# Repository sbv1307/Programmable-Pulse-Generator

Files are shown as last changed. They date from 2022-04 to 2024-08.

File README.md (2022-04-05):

# Programmable pulse generator for Arduino.
 The sketch will be build for Arduino NANO 

 The Programmable Pulse Generate will generate pulses on a number of output pins.

 ## Programming
 The Programmable Pulse Generate uses a REST approch over the serial connection (see below). 

  Programmeable parameters:
 - Number of output pins (with a maximum of 10).
 - Puls length in millis for each channel.
 - Puls period in millis for each channel.<span id="a1">[[1]](#f1)</span>
 - The pause between pulses in each channel "Pulse Order Interval".
 - Relation between pulses on the various channels (pulseOrder). 
   - Individual     'I' Pulses starts Simultaneously, but act upon their own pulse length and interval. (Default)
   - Simultaneously 'S' All pulses starts a the same time. Pulse interval is redefined to be the lognest pulse length plus the longest pulse interval.
   - Sequential     'Q' Pulses starts after another), with a programmable pause between the pulses (Pulse Order Interval). 
   - Randum         'R' Pulses starts randumly om each channel and follow their own length and interval.
 - The pulse length on each channel can be selected as LOW pulse or HIGH pulse.
 - Number of pulses fired on each channel. Initiated by a push button function attached to pin A5 (19).
   When the push button is pressed once, the pulse generator stops.
   When the push button is pressed twice, the pulse generator restarts, at fires the configured pulses on each channel.
   When the push button is pressed once, after it has been pushed twice, the pusle generator restarts and runs infinitly.
   
 ### **Firmware Version histoty:**
 * 1.2.4 - Bugfix: Cannot set pulseLength. [if ( value = 0 ... changed to  if ( value >= 0 ...] Value would never be zero:-)
 * 1.2.3 - Bugfix in Sequencial run and documentatino update
 * 1.2.2 - Parameter for programmelable delay after "Run Infinite" to "Run Limited"
 * 1.2.1 - Issues regarding configurations being changed, when Puls Order is changed from I to Q, S or R. handleRest() si change to reload the stored configuration, before adding changes.
 * 1.2.0 - Configuration bugfixes
 * 1.1.2 - Minor documentation corrections - No funktional changes

 * 1.1.0 - Adding push button funktionality, which will fire a configured number of pulses on each channel.
 * 1.0.0 - Prod. version.
 * 0.2.0 - Versions 0.2.x is for developing Programmable interface.
         - Taking the REST approch for programming parameters. 
 * 0.1.1 - Building in funktionality for handeling different "pulse orders".
         - pinState re-defined to match ACTIVE / PASSIVE pulse instead of LOW / HIGH.
 * 0.1.0 - Initial commit: Basic funktionalites are build in. No parameters are programmable, but the required program structure is in place.

#### REST Approch
 * Communication will be over serial connection (USB).
 * When not connected, the sketch will start, using the last programmed configuration.

/configurations/{parameret}/{id}/{value} or /configurations/{parameret}/{value} 

                <numberOfChannels>  /<1 - 10> 
                <pulseOrder>        /<I, S, Q or R>
                <pulseOrderInterval>/<millisecunds>
                <pulseLength>       /<channel 1-10>/<millisecunds>
                <pulsePeriod>       /<channel 1-10>/<millisecunds>
                <pulseActive>       /<channel 1-10>/<LOW or HIGH>
                <numberOfPulses>    /<channel 1-10>/<1 - 100000>
                setDefaults

 ##### Configuration examaples:
 * configurations/numberOfChannels/3
 * configurations/pulseOrder/S
 * configurations/pulseOrderInterval/250
 * configurations/pulseLength/1/100
 * configurations/pulsePeriod/1/500<span id="a1">[[1]](#f1)</span>
 * configurations/pulseActive/1/HIGH
 * configurations/numberOfPulses/1/1000
 * configurations/setDefaults

##### Ardhino nano Pin definition/layout:***
 * Pin  0: Serial RX
 * Pin  1: Serial TX
 * Pin  2: Channel pin 1:
 * Pin  3: Channel pin 2: 
 * Pin  4: Channel pin 3:
 * Pin  5: Channel pin 4:
 * Pin  6: Channel pin 5:
 * Pin  7: Channel pin 6:
 * Pin  8: Channel pin 7:
 * Pin  10: Channel pin 9:
 * Pin  11: Channel pin 10:
 * Pin  12: Channel pin 11:
 * Pin  13: LED_BUILTIN. 
 * Pin  14: (A0): RANDUM_SEED_PIN    Used for randumSeed() to generate different seed numbers each time the sketch runs.
 * Pin  15: (A1): N/C
 * Pin  16: (A2): N/C
 * Pin  17: (A3): N/C
 * Pin  18: (A4): N/C
 * Pin  19: (A5): Button pin. Button to running in non continoougious mode (file configured numer of pulses)

### Project eligibility. 
The sketch was build for simulating the pulses on the open collector outputs on a number of Carlo Gavazzi energy meters Type EM23 DIN and Type EM111.
The project "EnergyRegistgration", which are build to register pulses on the open collector output on the above mentined meters has a problem, counting the pulses corectly. Some pulses are rigistered but not counted and some are counted too many.
This project is to investigate into this problem.

##### 1. <span id="f1"></span>Note: If pulseOrder is set to 'Q', puls period on channel 1 will define the pause from the last puls in the sequence to the first starts. 

### **Project Version History:**
2.0.0 - Hardware merged with Firmware (initial product version)

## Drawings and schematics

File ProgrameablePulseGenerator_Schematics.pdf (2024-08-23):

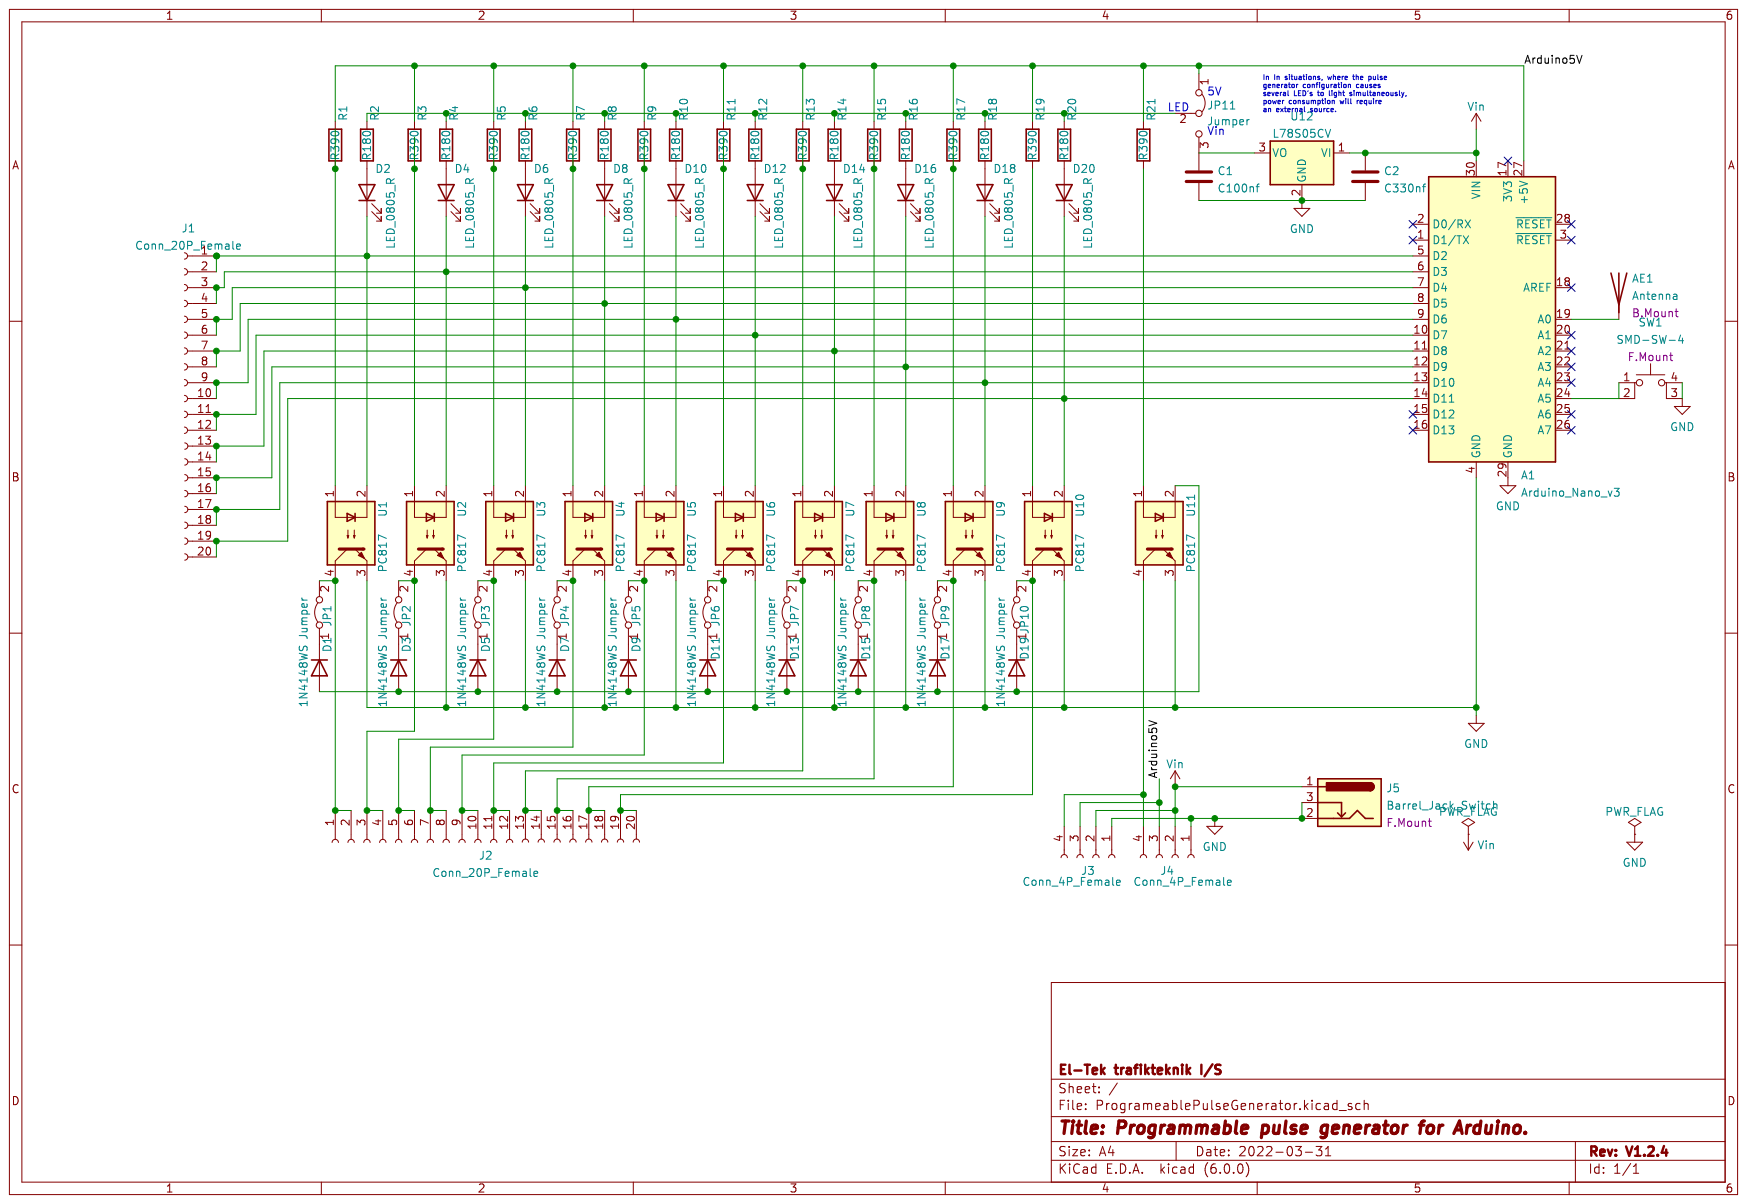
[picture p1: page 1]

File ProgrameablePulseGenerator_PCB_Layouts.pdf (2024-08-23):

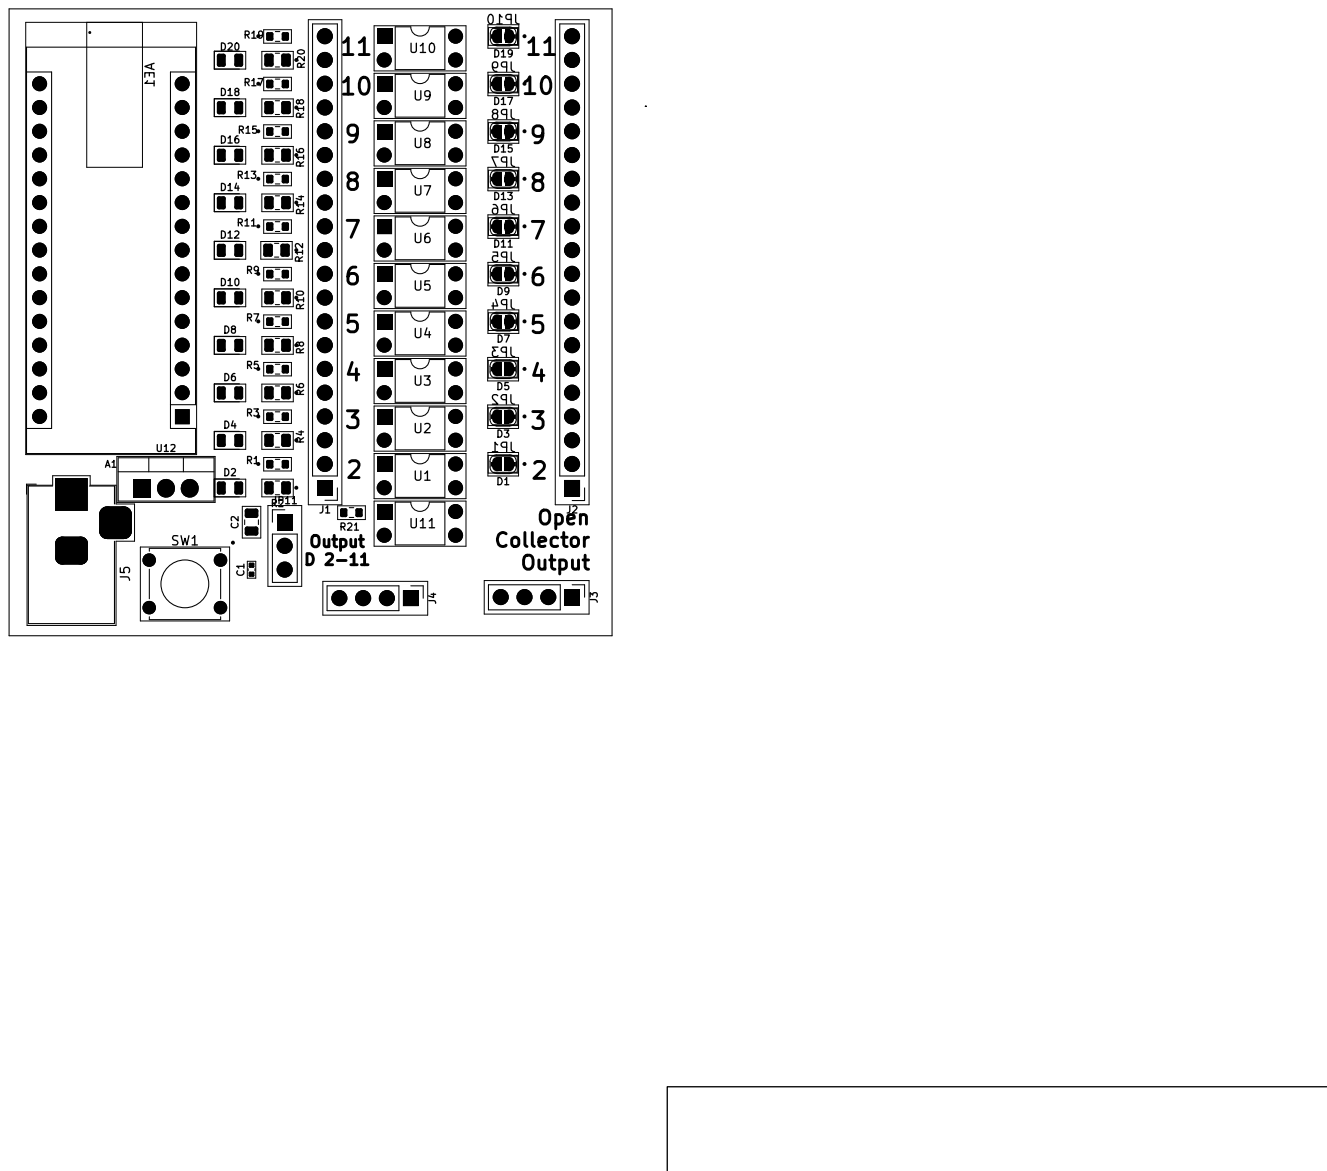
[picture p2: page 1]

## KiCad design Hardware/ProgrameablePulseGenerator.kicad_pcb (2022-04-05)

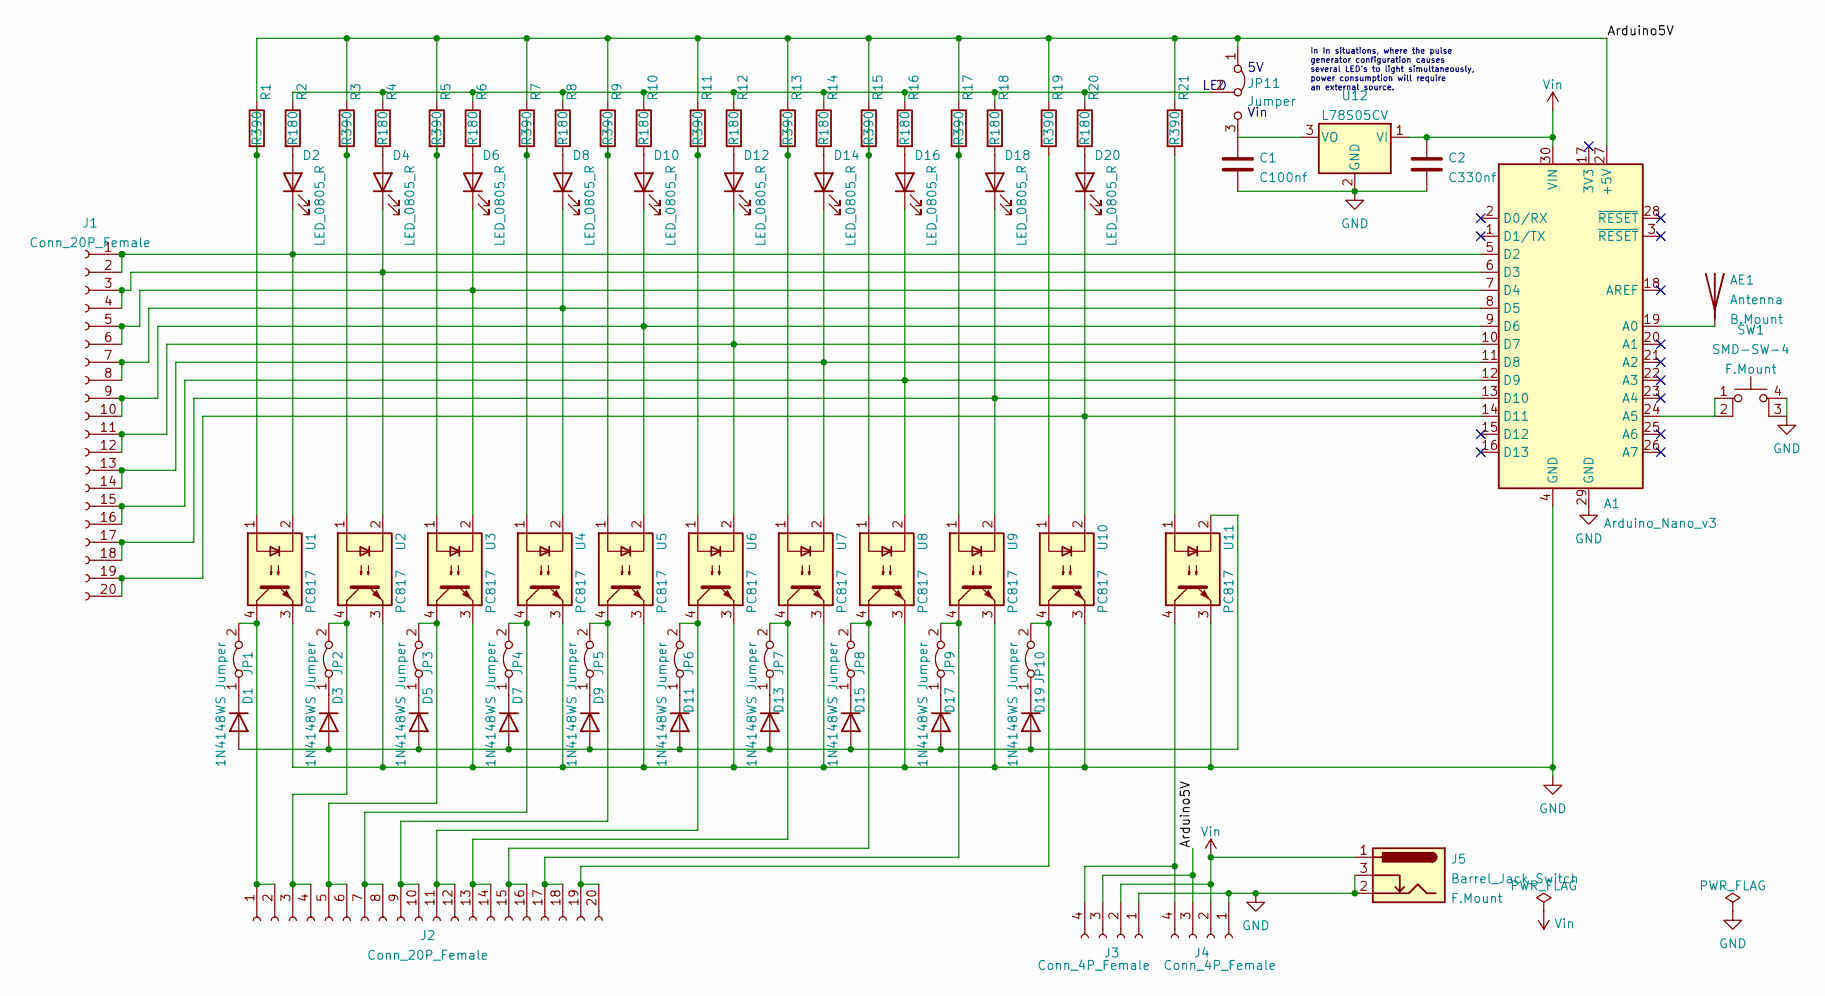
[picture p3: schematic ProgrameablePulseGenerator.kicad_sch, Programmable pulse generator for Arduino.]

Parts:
A1: Arduino_Nano_v3; Arduino_Nano; MFR. Part # A000005; Digi-Key Part # 1050-1001-ND
AE1: Antenna; Undefined_Antenna(B.Mount)
C1: C100nf; C_0402_1005Metric; MFR. Part # CL05B104KO5NNNC; JLCPCB Part # C1525
C2: C330nf; C_0805_2012Metric; MFR. Part # 0805B334K500NT; JLCPCB Part # C1740
D1, D3, D5, D7, D9, D11, D13, D15, D17, D19: 1N4148WS; D_SOD-323F; MFR. Part # 1N4148WS; JLCPCB Part # C2128
D2, D4, D6, D8, D10, D12, D14, D16, D18, D20: LED_0805_R; LED_0805_2012Metric; MFR. Part # NCD0805R1; JLCPCB Part # C84256
J1, J2: Conn_20P_Female; PinHeader_1x20_P2.54mm_Vertical; MFR. Part # 4155; Digi-Key Part # 1528-2927-ND
J3, J4: Conn_4P_Female; PinHeader_1x04_P2.54mm_Vertical; MFR. Part # 4155; Digi-Key Part # 1528-2927-ND
J5: Barrel_Jack_Switch; BarrelJack_Horizontal(F.Mount); MFR. Part # PJ-058AH; Digi-Key Part # CP-058AH-ND
JP1, JP2, JP3, JP4, JP5, JP6, JP7, JP8, JP9, JP10: Jumper; SolderJumper-2_P1.3mm_Bridged_RoundedPad1.0x1.5mm(B.Mount)
JP11: Jumper; PinHeader_1x03_P2.54mm_Vertical
R1, R3, R5, R7, R9, R11, R13, R15, R17, R19, R21: R390; R_0603_1608Metric; MFR. Part # 0603WAF3900T5E; JLCPCB Part # C23151
R2, R4, R6, R8, R10, R12, R14, R16, R18, R20: R180; R_0805_2012Metric; MFR. Part # 0805W8F1800T5E; JLCPCB Part # C25270
SW1: SMD-SW-4; SW_Tactile_Straight_(F.Mount); MFR. Part # TS-1187A-B-A-B; JLCPCB Part # C318884
U1, U2, U3, U4, U5, U6, U7, U8, U9, U10, U11: PC817; DIP-4_W7.62mm_Slim
U12: L78S05CV; TO-220-3_Vertical; MFR. Part # L78S05CV; Digi-Key Part # 497-1468-5-ND

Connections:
/Arduino5V: A1.27 (+5V), J3.3, J4.3, JP11.1 (A), R1.1, R3.1, R5.1, R7.1, R9.1, R11.1, R13.1, R15.1, R17.1, R19.1, R21.1
GND: A1.4 (GND), A1.29 (GND), C1.2, C2.2, J3.1, J4.1, J5.2, J5.3, SW1.3 (K), SW1.4 (A), U1.3, U2.3, U3.3, U4.3, U5.3, U6.3, U7.3, U8.3, U9.3, U10.3, U11.3, U12.2 (GND)
unnamed: A1.5 (D2), D2.1 (K), J1.1, J1.2, U1.2
unnamed: A1.6 (D3), D4.1 (K), J1.3, J1.4, U2.2
unnamed: A1.7 (D4), D6.1 (K), J1.5, J1.6, U3.2
unnamed: A1.8 (D5), D8.1 (K), J1.7, J1.8, U4.2
unnamed: A1.9 (D6), D10.1 (K), J1.9, J1.10, U5.2
unnamed: A1.10 (D7), D12.1 (K), J1.11, J1.12, U6.2
unnamed: A1.11 (D8), D14.1 (K), J1.13, J1.14, U7.2
unnamed: A1.12 (D9), D16.1 (K), J1.15, J1.16, U8.2
unnamed: A1.13 (D10), D18.1 (K), J1.17, J1.18, U9.2
unnamed: A1.14 (D11), D20.1 (K), J1.19, J1.20, U10.2
unnamed: A1.19 (A0), AE1.1 (A)
unnamed: A1.24 (A5), SW1.1, SW1.2
unnamed: C1.1, JP11.3 (B), U12.3 (VO)
unnamed: D1.1 (K), JP1.1 (A)
unnamed: D1.2 (A), D3.2 (A), D5.2 (A), D7.2 (A), D9.2 (A), D11.2 (A), D13.2 (A), D15.2 (A), D17.2 (A), D19.2 (A), U11.2
unnamed: D2.2 (A), R2.2
unnamed: D3.1 (K), JP2.1 (A)
unnamed: D4.2 (A), R4.2
unnamed: D5.1 (K), JP3.1 (A)
unnamed: D6.2 (A), R6.2
unnamed: D7.1 (K), JP4.1 (A)
unnamed: D8.2 (A), R8.2
unnamed: D9.1 (K), JP5.1 (A)
unnamed: D10.2 (A), R10.2
unnamed: D11.1 (K), JP6.1 (A)
unnamed: D12.2 (A), R12.2
unnamed: D13.1 (K), JP7.1 (A)
unnamed: D14.2 (A), R14.2
unnamed: D15.1 (K), JP8.1 (A)
unnamed: D16.2 (A), R16.2
unnamed: D17.1 (K), JP9.1 (A)
unnamed: D18.2 (A), R18.2
unnamed: D19.1 (K), JP10.1 (A)
unnamed: D20.2 (A), R20.2
unnamed: J2.1, J2.2, JP1.2 (B), U1.4
unnamed: J2.3, J2.4, JP2.2 (B), U2.4
unnamed: J2.5, J2.6, JP3.2 (B), U3.4
unnamed: J2.7, J2.8, JP4.2 (B), U4.4
unnamed: J2.9, J2.10, JP5.2 (B), U5.4
unnamed: J2.11, J2.12, JP6.2 (B), U6.4
unnamed: J2.13, J2.14, JP7.2 (B), U7.4
unnamed: J2.15, J2.16, JP8.2 (B), U8.4
unnamed: J2.17, J2.18, JP9.2 (B), U9.4
unnamed: J2.19, J2.20, JP10.2 (B), U10.4
unnamed: J3.4, J4.4, U11.4
unnamed: JP11.2 (C), R2.1, R4.1, R6.1, R8.1, R10.1, R12.1, R14.1, R16.1, R18.1, R20.1
unnamed: R1.2, U1.1
unnamed: R3.2, U2.1
unnamed: R5.2, U3.1
unnamed: R7.2, U4.1
unnamed: R9.2, U5.1
unnamed: R11.2, U6.1
unnamed: R13.2, U7.1
unnamed: R15.2, U8.1
unnamed: R17.2, U9.1
unnamed: R19.2, U10.1
unnamed: R21.2, U11.1
Vin: A1.30 (VIN), C2.1, J3.2, J4.2, J5.1, U12.1 (VI)

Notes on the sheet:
LED
In In situations, where the pulse generator configuration causes several LED's to light simultaneously, power consumption will require an external source.
Vin

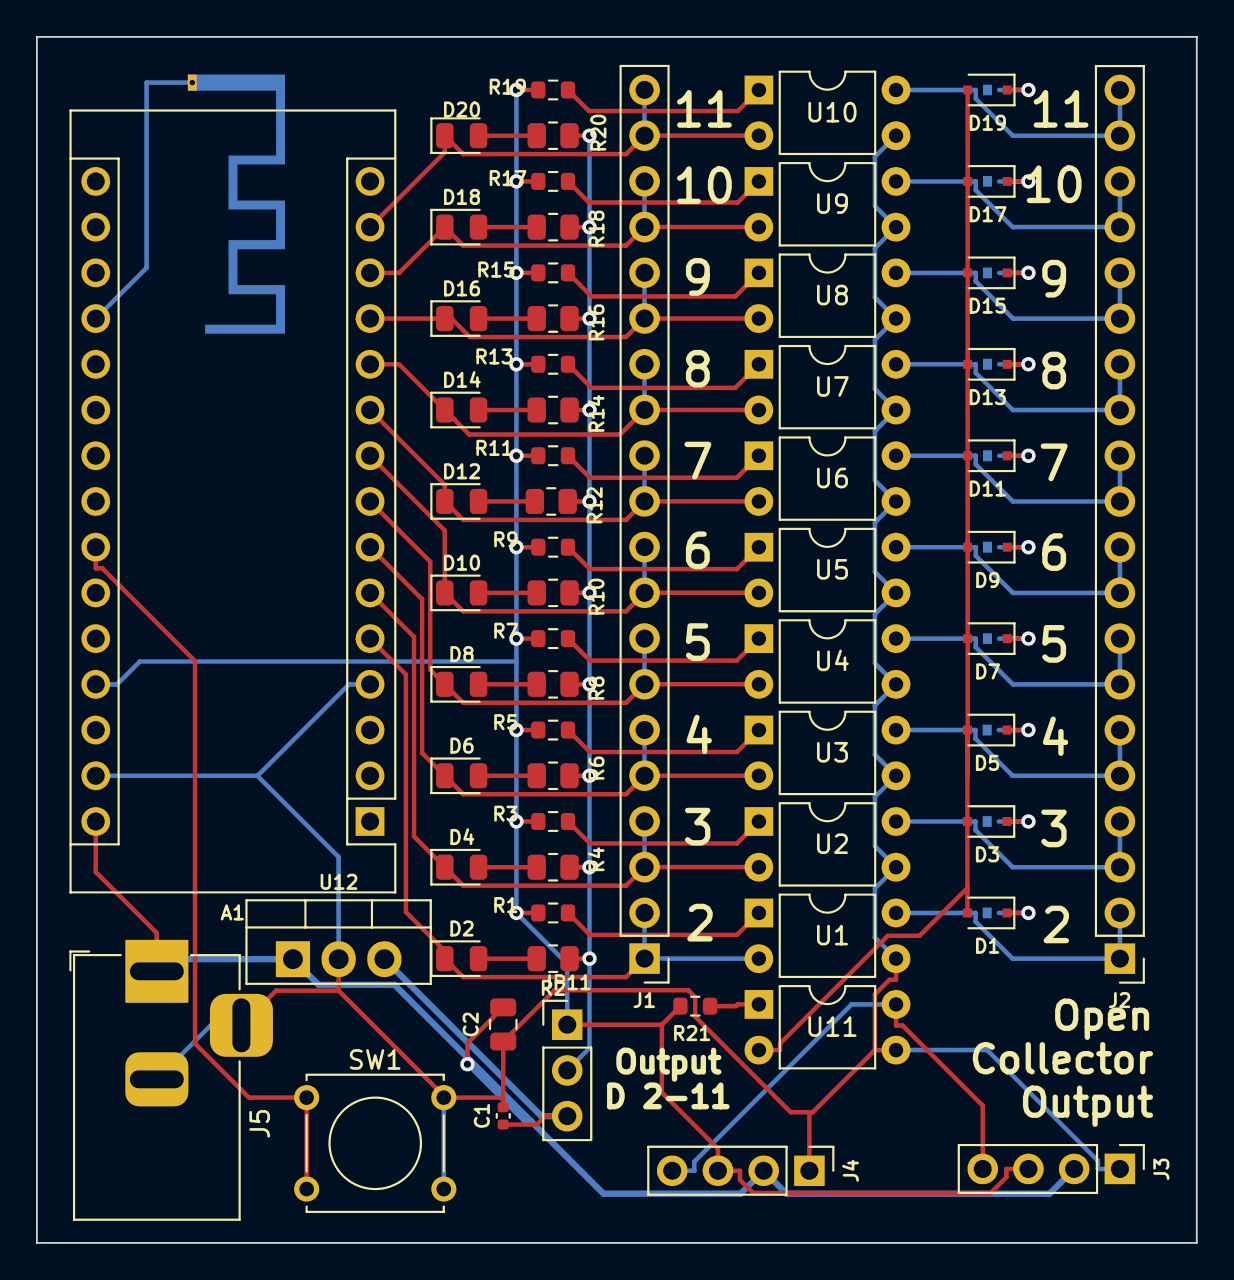
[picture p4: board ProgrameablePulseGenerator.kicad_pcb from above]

Board: 2 copper layers, 64.4 x 67.0 mm, 74 parts (0 on the bottom side), 60 nets.

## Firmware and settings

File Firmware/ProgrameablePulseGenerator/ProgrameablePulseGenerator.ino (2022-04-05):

/*
 * Programable puls generator.
 * 
 * It will generate pulses on a number of output pins. 
 * 
 * Programmable parameters:
 * Parameters are and their defaults:
 * - Number of 
 * channels (MAX 10):           1 
 * - Pulse length in millis:                50
 * - Pulse interval in millis:              1000
 * - Pulse order interval in millis:        250
 * - Number of pulses:                      1
 * - Run continously:                       true
 * - Pulse (the short part / Active part):  LOW
 * - Pulse order:                           Individual (I) 
 *  
 * - Pulse order - Relation between pulses on the various channels. 
 *   : Individual 'I' Pulses act upon their own pulse length and interval (Default).
 *   : Sequential 'Q' Pulses starts after another), with a programmable pause (Pulse order interval) between the pulses. 
 *   : Simultaneously 'S' All pulses starts a the same time.
 *   : Randum 'R' Pulses starts randumly om each channel and follow their own length and interval.
 * 
 */
#define SKETCH_VERSION "Programable puls generator - Version 1.2.4"

/*
 *    Define DEBUGGING
 */
// #define DEBUG       //If defined ("//" is removed at the beginning of this line.) debug informations are printed to Serial.
// #define PULSE_DEBUG // If defined output state for each channel is displayed. (Gives a lot of output...) 
/*
 * Version history:
 * 1.2.4 - Bugfix: Cannot set pulseLength. [if ( value = 0 ... changed to  if ( value >= 0 ...] Value would never be zero:-)
 * 1.2.3 - Bugfix in Sequencial run and documentatino update
 * 1.2.2 - Parameter for programmelable delay after "Run Infinite" to "Run Limited"
 * 1.2.1 - Issues regarding configurations being changed, when Puls Order is changed from I to Q, S or R. handleRest() si change to reload the stored configuration, before adding changes.
 * 1.2.0 - Configuration bugfixes - Configuration defaults change to confiture alle MAX_NUMBER_OF_CHANNELS channels.
 * 1.1.2 - Minor documentation corrections - No funktional changes
 * 1.1.1 - Documentation update - No funktional changes
 * 1.1.0 - Adding push button funktionality, which will fire a configured number of pulses on each channel. 
 *       - Configuration structure is changed.
 * 1.0.0 - Prod. version.
 * 0.2.0 - Versions 0.2.x is for developing Programmable interface.
 *       - 
 * 0.1.1 - Building in funktionality for handeling different "pulse orders".
 * 0.1.0 - Initial commit: Basic funktionalites are build in. No parameters are programmable, but the required program structure is in place.
 * 
 * 
 *  **** Ardhino nano Pin definition/layout:***
 * Pin  D0: Serial RX
 * Pin  D1: Serial TX
 * Pin  D2: Channel pin 1:
 * Pin  D3: Channel pin 2: 
 * Pin  D4: Channel pin 3:
 * Pin  D5: Channel pin 4:
 * Pin  D6: Channel pin 5:
 * Pin  D7: Channel pin 6:
 * Pin  D8: Channel pin 7:
 * Pin  D10: Channel pin 9:
 * Pin  D11: Channel pin 10:
 * Pin  D12: Channel pin 11:
 * Pin  D13: LED_BUILTIN. 
 * Pin  D14: (A0): RANDUM_SEED_PIN    Used for randumSeed() to generate different seed numbers each time the sketch runs.
 * Pin  D15: (A1): N/C
 * Pin  D16: (A2): N/C
 * Pin  D17: (A3): N/C
 * Pin  D18: (A4): N/C
 * Pin  D19: (A5): Button pin. Button to running in non continoougious mode (file configured numer of pulses)
 */
#include <EEPROM.h>
#include "EEPROMAnything.h"


 /*
 * ######################################################################################################################################
 *                       C  O  N  F  I  G  U  T  A  B  L  E       D  E  F  I  N  I  T  I  O  N  S
 * ######################################################################################################################################
*/
#define CONFIGURATION_VERSION 4
#define MAX_NUMBER_OF_CHANNELS 10
#define RANDUM_SEED_PIN 0
#define BUTTON_PIN 19
#define CONFIG_ADDRESS 0

#define ACTIVE  0X1                               // Could ofcause use HIGH / LOW, but it makes more sense to define ACTIVE and PASSIVE as
#define PASSIVE 0x0                               // ACTIVE can be a LOW pulse or a HIGH pulse. 

/*
 *  #####################################################################################################################
 *                       V  A  R  I  A  B  L  E      D  E  F  I  N  A  I  T  O  N  S
 *  #####################################################################################################################
 */
/* Incapsulate strings i a P(string) macro definition to handle strings in PROGram MEMory (PROGMEM) to reduce valuable memory  
 * MACRO for string handling from PROGMEM
 * https://todbot.com/blog/2008/06/19/how-to-do-big-strings-in-arduino/
 * max 149 chars at once ...
 * ----------------------------------------------------------------------------------------------------------------------------------------------------- (149 characters)
 */
 char p_buffer[150];
#define P(str) (strcpy_P(p_buffer, PSTR(str)), p_buffer)

const int channelPin[MAX_NUMBER_OF_CHANNELS] = { 2, 3, 4, 5, 6, 7, 8, 9, 10, 11};

unsigned long channelTimeStamp[MAX_NUMBER_OF_CHANNELS];
unsigned long channelOffsetStartTime[MAX_NUMBER_OF_CHANNELS];
int numberOfPulses[MAX_NUMBER_OF_CHANNELS];

uint8_t pinState[MAX_NUMBER_OF_CHANNELS];           // A flag for storing the last state (Active / Passive) for the actual pin

// Variables for controlling button input
int lastButtonState = HIGH;   // the previous reading from the input pin
boolean buttonPressedOnce = false;

// the following variables are unsigned longs because the time, measured in
// milliseconds, will quickly become a bigger number than can be stored in an int.
unsigned long lastDebounceTime = 0;  // the last time the output pin was toggled
unsigned long debounceDelay = 250;    // the debounce time; increase if the output flickers


struct config_t                                     // Configuration are stored in a structure, and read from EEPROM. If no available, default parameters are written.
  {
    int structVersion;                              //A way to determind the correct confiugration structure.
    int numberOfChannels;
    int numberOfPulses[MAX_NUMBER_OF_CHANNELS];               //Number of pulses fired, when push button is pushed twice.
    boolean runContinous;                                     //When bottun is pushed twice, this will tuggle between true and false.
    unsigned long runlimitedDelay;                            // the number of miliconds before the pulesgenerator starts, after configuration has change to "Run Limited"        
    char pulseOrder;                                          //A character value, which describe Simultaneously (S), Sequential (Q), Randum (R) 
    unsigned long pulseOrderInterval ;                        //In Sequentially mode a value between the pulses on each channel
    unsigned long pulseLength[MAX_NUMBER_OF_CHANNELS];        //Puls Length is in millisecunds.
    unsigned long pulseInterval[MAX_NUMBER_OF_CHANNELS];      //Number of pulses per minut is re-calculated and stored as millisecunds between eash pulse
    uint8_t pulseActive[MAX_NUMBER_OF_CHANNELS];              //Defined with HIGH or LOW weather the active part of the pulse is HIGH or LOW
    uint8_t pulsePassive[MAX_NUMBER_OF_CHANNELS];             //Defined with HIGH or LOW weather the passive part of the pulse is HIGH or LOW
  } configuration;
/*
 * ###################################################################################################
 *                       F  U  N  C  T  I  O  N      D  E  F  I  N  I  T  I  O  N  S
 * ###################################################################################################
*/
void(* resetFunc) (void) = 0;//declare reset function at address 0

void setConfigurationDefaults() {
                                                              #ifdef DEBUG
                                                                Serial.println(P("Setting configuration defaultes!"));
                                                              #endif
  
  configuration.structVersion = CONFIGURATION_VERSION * 100 + MAX_NUMBER_OF_CHANNELS;
  configuration.numberOfChannels = MAX_NUMBER_OF_CHANNELS;
  configuration.runContinous = true;                            //Default run continously. if false only the configured number of pulses will be fired
  configuration.runlimitedDelay = 5000;                         // Default: wait five secunds before restarting after configuration has changed to "Run Limited"
  for ( int ii = 0; ii < configuration.numberOfChannels; ii++) {
    configuration.pulseLength[ii] = 50;
    configuration.pulseInterval[ii] = 950;
    configuration.numberOfPulses[ii] = 10;
    configuration.pulseActive[ii] = LOW;                                  // This define if the pulse is active LOW or active HIGH
    if ( configuration.pulseActive[ii] == LOW )
      configuration.pulsePassive[ii] = HIGH;                                // Needs to be the oppersit ove active!
    else
      configuration.pulsePassive[ii] = LOW;
  }
  configuration.pulseOrder = 'I';
  configuration.pulseOrderInterval = 250;
  int charsWritten = EEPROM_writeAnything( CONFIG_ADDRESS, configuration);
                                                              #ifdef DEBUG
                                                                if ( charsWritten == sizeof( configuration))
                                                                  Serial.println(P("Configuration sucessfully written to EEMPROM"));
                                                                else
                                                                  Serial.println(P("F A I L E D   Writing configuration to EEPROM"));
                                                              #endif
}

void printConfiguration() {
  Serial.print(P("\n\nStructure version: "));
  Serial.println(configuration.structVersion);
  Serial.print(P("Number of channels: "));
  Serial.println(configuration.numberOfChannels);
  for ( int ii = 0; ii < configuration.numberOfChannels; ii++) {
    Serial.print(P("Channel "));
    Serial.print(ii +1);
    Serial.print(P(" Pulse length: "));
    Serial.print(configuration.pulseLength[ii]);
    Serial.print(P(" Pulse period: "));
    Serial.print(configuration.pulseInterval[ii] + configuration.pulseLength[ii]);
    Serial.print(P(" Pulse active: "));
    if ( configuration.pulseActive[ii] == HIGH)
      Serial.print(P("HIGH"));
    else
      Serial.print(P("LOW"));
    Serial.print(P(". Number of pulses generated if Limited run: "));
    Serial.println( configuration.numberOfPulses[ii]);
  }
  if ( configuration.runContinous)
    Serial.println(P("Run Infinite. PRESS pushbutton twice to change!"));
  else
    Serial.println(P("Run Limited. PRESS pushbutton once to change!"));
  Serial.print(P("Delay restart when configuration changed to Run Limited for (miliconds): "));
  Serial.println(configuration.runlimitedDelay);  
  Serial.print(P("Pulse order: "));
  Serial.println(configuration.pulseOrder);
  Serial.print(P("Pulse order interval: "));
  Serial.println(configuration.pulseOrderInterval);
  Serial.print(P("Connect Pushbutton to pin#: "));
  Serial.println(BUTTON_PIN);
  Serial.println(P("\n\nHit <Enter> to get help!"));
}

/*
 * Handle REST function.
 * Expected character string:
 * /configurations/{parameret}/{id}/{value}, /configurations/{parameret}/{value} or configurations/{parameret}/ 
 * 
 *                <numberOfChannels>  /<1 - 10> 
 *                <pulseOrder>        /<I, S, Q or R>
 *                <runlimitedDelay>   /<millisecunds>
 *                <pulseOrderInterval>/<millisecunds>
 *                <pulseLength>       /<channel 1-10>/<millisecunds>
 *                <pulsePeriod>       /<channel 1-10>/<millisecunds>
 *                <pulseActive>       /<channel 1-10>/<LOW or HIGH>
 *                <setDefaults>       /
 *
 * Configuration examaples:
 * configurations/numberOfChannels/3
 * configurations/pulseOrder/S
 * configurations/runlimitedDelay/5000
 * configurations/pulseOrderInterval/250
 * configurations/pulseLength/1/100
 * configurations/pulsePeriod/1/500
 * configurations/pulseActive/1/HIGH
 * configurations/setDefaults/
 * 
 *
 */
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
void loop() {

  /*
   * <<<<<<<<<<<<<<<<<<<<<<<<<<<<  Pulse generation section >>>>>>>>>>>>>>>>>>>>>>>>>>>>>>>>>>>>>>>>>>><
   */
  unsigned long currentTimeStamp = millis();

  for ( int ii = 0; ii < configuration.numberOfChannels; ii++) {
    if ( pinState[ii] == PASSIVE && currentTimeStamp - channelTimeStamp[ii] > configuration.pulseInterval[ii] + channelOffsetStartTime[ii] && numberOfPulses[ii] > 0) {
      if ( ii == 0)
        digitalWrite( LED_BUILTIN, HIGH);

                                                              #ifdef PULSE_DEBUG
                                                                Serial.print("Channel [");
                                                                Serial.print(ii);
                                                                Serial.println("] Active");
                                                              #endif
       
      digitalWrite( channelPin[ii], configuration.pulseActive[ii]);
      pinState[ii] = ACTIVE;
      channelTimeStamp[ii] = currentTimeStamp; 
      channelOffsetStartTime[ii] = 0;
      if ( !configuration.runContinous) {
        numberOfPulses[ii]--;
        if ( numberOfPulses[ii] == 0) {
          Serial.print(configuration.numberOfPulses[ii]);
          Serial.print(P(" pulses fired on channel ["));
          Serial.print(ii + 1);
          Serial.println(P("]. Press push button once to continue or twice to restart!"));
        }
      } 
        
      
   } else if ( pinState[ii] == ACTIVE && currentTimeStamp - channelTimeStamp[ii] > configuration.pulseLength[ii]){
       
      if ( ii == 0)
        digitalWrite( LED_BUILTIN, LOW );
        
                                                              #ifdef PULSE_DEBUG
                                                                Serial.print("Channel [");
                                                                Serial.print(ii);
                                                                Serial.println("] Passive");
                                                              #endif

    digitalWrite( channelPin[ii], configuration.pulsePassive[ii]);
      pinState[ii] = PASSIVE;
      channelTimeStamp[ii] = currentTimeStamp;
    }
  }

  /*
   * <<<<<<<<<<<<<<<<<<<<<<<<<<<<  Push button section >>>>>>>>>>>>>>>>>>>>>>>>>>>>>>>>>>>>>>>>>>><
   */

  // read the state of the switch into a local variable:

  int currentButtonState = digitalRead( BUTTON_PIN);
  
  // check to see if you just pressed the button
  // (i.e. the input went from LOW to HIGH), and you've waited long enough
  // since the last press to ignore any noise:

  // If the switch changed, due to noise or pressing:
  if (currentButtonState == LOW and currentButtonState != lastButtonState) {
    // reset the debouncing timer
    lastDebounceTime = millis();
    lastButtonState = currentButtonState;
  } else if ( lastButtonState != currentButtonState) {
    if ((millis() - lastDebounceTime) > debounceDelay) {
                                                              #ifdef DEBUG
                                                                Serial.println(P("Button pressed"));
                                                              #endif
      if ( buttonPressedOnce) {
                                                              #ifdef DEBUG
                                                                Serial.println(P("Button pressed twice"));
                                                              #endif
      buttonPressedOnce = false;
      int charsRead = EEPROM_readAnything( CONFIG_ADDRESS, configuration);
      configuration.runContinous = false;
      int charsWritten = EEPROM_writeAnything( CONFIG_ADDRESS, configuration);
                                                              #ifdef DEBUG
                                                                if ( charsWritten == sizeof( configuration))
                                                                  Serial.println(P("Intermittent run written to configuration.\n\nRestarting...\n\n"));
                                                                else
                                                                  Serial.println(P("F A I L E D   Writing configuration to EEPROM"));
                                                              #endif
      Serial.print(P("\nRestarting in "));
      Serial.print(configuration.runlimitedDelay);
      Serial.println(P(" mililconds..."));
      delay(configuration.runlimitedDelay);
      resetFunc();                                  // Call reset, to start pulse generator with new configuration.

      } else {
        int charsRead = EEPROM_readAnything( CONFIG_ADDRESS, configuration);
        if (configuration.runContinous == false) {
          configuration.runContinous = true;
          int charsWritten = EEPROM_writeAnything( CONFIG_ADDRESS, configuration);
                                                              #ifdef DEBUG
                                                                if ( charsWritten == sizeof( configuration))
                                                                  Serial.println(P("Continous run written to configuration.\n\nRestarting...\n\n"));
                                                                else
                                                                  Serial.println(P("F A I L E D   Writing configuration to EEPROM"));
                                                              #endif
      
          delay(1000);
          resetFunc();                                  // Call reset, to start pulse generator with new configuration.
        }
        buttonPressedOnce = true;
        lastButtonState = currentButtonState;
      }
      for ( int ii; ii < configuration.numberOfChannels; ii++)
        numberOfPulses[ii] = 0;
    }
  }

  /*
   * <<<<<<<<<<<<<<<<<<<<<<<<<<<<<<<<<<  Programming section  >>>>>>>>>>>>>>>>>>>>>>>>>>>>>>>>>>>>>
   */
  if ( Serial.available())
    handleRest();
}

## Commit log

2020-12-10 * 1.1.0 - Adding push button funktionality, which will fire a configured number of pulses on each channel.
2022-01-27 Ver. 1.2.3 - Sequential bug fixes and documentation updates
    [ProgrameablePulseGenerator.ino]
2022-02-15 Bugfix: Could not set pulse length
    [ProgrameablePulseGenerator.ino]
2022-03-30 Arduino files replaced and .gitignore updated to manage future Arduinio and KiCad working files
    [ProgrameablePulseGenerator.ino]
2022-03-30 Initial commit for rearagen and HW add on
    [ProgrameablePulseGenerator.kicad_pcb, ProgrameablePulseGenerator.kicad_sch]
2022-04-05 Hardware merged with Firmware (initial product version)
    [ProgrameablePulseGenerator.kicad_pcb, ProgrameablePulseGenerator.kicad_sch]
